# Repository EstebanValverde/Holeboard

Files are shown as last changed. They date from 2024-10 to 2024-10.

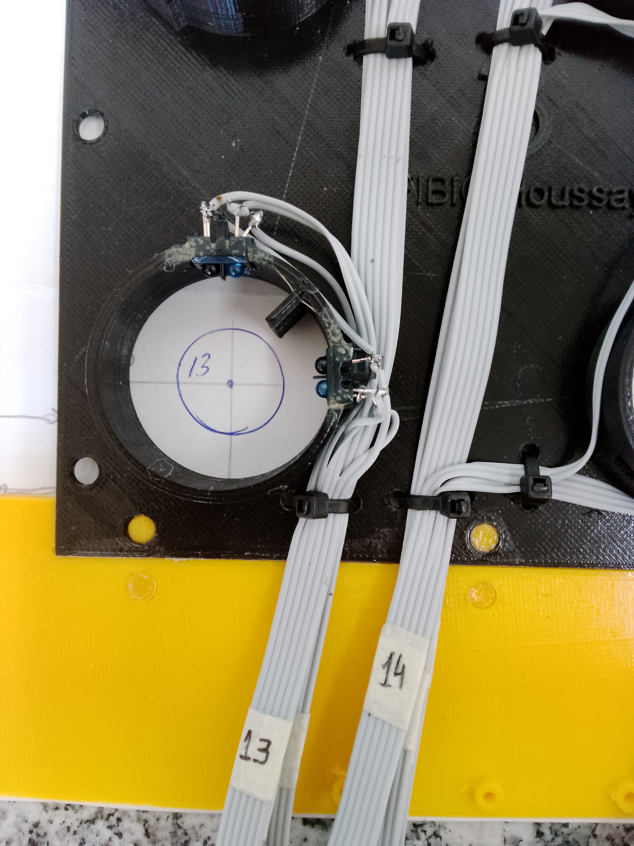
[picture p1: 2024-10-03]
photos/IMG_20231116_135203.jpg

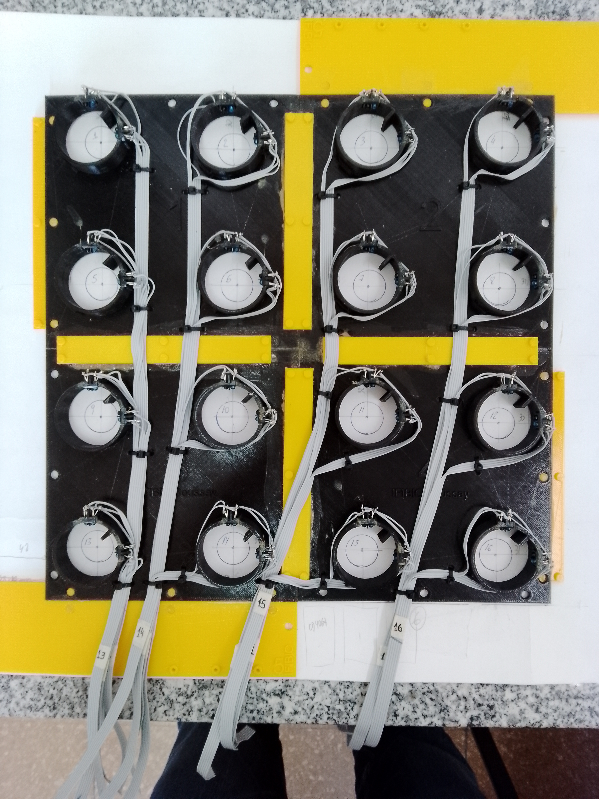
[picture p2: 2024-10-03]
photos/IMG_20231116_135154.jpg

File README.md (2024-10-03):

# Holeboard for mice behavior
The holeboard test (HBT), using a dual-beam infrared system, tracks the behavior (anxiety, stress, neophilia, emotionality) of rodents on a 4x4 grid of holes. Each time the rodent inspects a hole, the device records it, measures the time of the event and its duration, and stores it in a micro SD memory for later analysis. In addition, the device has a TTL-type logic output to synchronize with a video tracking system that records the animal's movement on the grid. As a novelty, this particular HBT has a manual adjustment of the detection threshold and a reading of the grid's basal level. This, on the one hand, allows it to be independent of ambient light conditions, and on the other, to adjust the sensitivity in the detection of an inspection.



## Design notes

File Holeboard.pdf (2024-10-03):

CPA Responsable
Dr. Esteban Valverde

ORDEN DE PROVISIÓN DE SERVICIOS - CPA Nº de ticket

Desarrollo y diagnóstico tecnológico para las
diferentes líneas de investigación
Fecha de Inicio: 10/06/2023 | Fecha de Finalización: 01/02/2024

## Desarrollo de la orden de servicio

### Descripción general

Este Holeboard en particular es un dispositivo de 16 agujeros (Holes), distribuidos en cuatro filas y cuatro columnas, tal y como se observa en la Fig. 1.

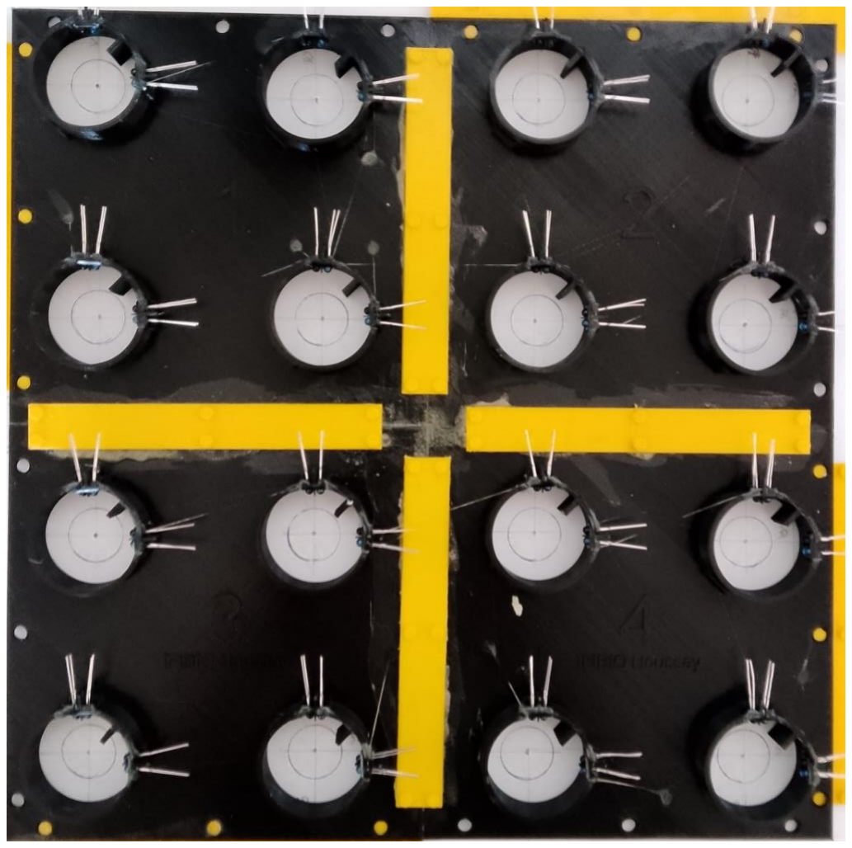
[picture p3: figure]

Figura 1: Vista superior del Holeboard

A su vez, cada “Hole” cuenta con dos sensores infrarrojos TCRT5000 (ver Fig. 2), de manera de detectar cuando el roedor mete la cabeza dentro del agujero. El uso de dos sensores en cada agujero se debe a que pruebas experimentales mostraron que un solo sensor no alcanza para cubrirlo por completo, quedando zonas del Hole que el sensor no detecta.

Como se observa en la Fig. 2, cada Hole tiene un diámetro de 2cm, mientras que el espacio interior debajo del Hole tiene un diámetro de 36cm y una profundidad de 1.5cm, de manera que los sensores quedan dentro de ese espacio. A su vez, los sensores están separados por una pared divisoria para evitar que el emisor de un sensor impacte en el receptor del otro sensor y perjudique la medición.

Se debe notar que el espacio interior de cada Hole es negro, ya que pruebas preliminares mostraron que este color es la mejor condición para el registro, esto es, la NO detección de IR cuando no hay ningún objeto dentro del hole, o mejor dicho, la sensibilidad de detectar cuando el ratón mete la nariz en el hole.

diferentes líneas de investigación

Fecha de Inicio: 10/06/2023 | Fecha de Finalización: 01/02/2024

Además, fue necesario pintar de negro el lado de interno de la tapa del holeboard, por esta misma razón, mientras que el lado superior (externo) quedó blanco para poder seguir mejor con la cámara el movimiento del roedor. Para lograr tener blanco de una lado y negro del otro, primeramente se pintó de blanco mate, con 4 capas, el lado inferior de la tapa del holeboard y sobre esta se dieron dos capas de negro mate, de manera de cubrir toda la superficie. Así, el lado superior, de acrílico blanco semitransparente, se observa blanco y sin pintar, cosa que permite que los roedores deambulen sin el peligro de que empiecen a roer la pintura, y el lado inferior queda completamente negro, cosa que favorece el no reborte del IR dentro de cada hole cuando no hay objetos dentro del hole.

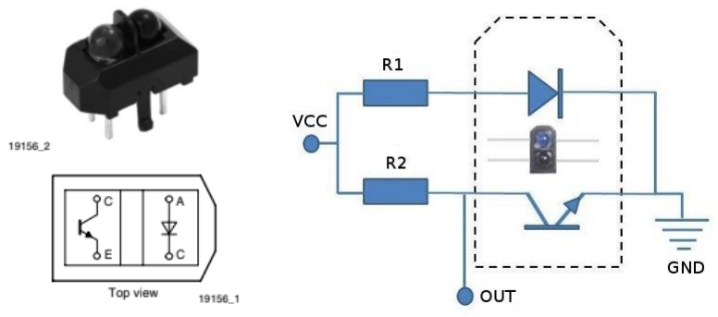
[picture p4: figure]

Figura 2. Detalle de cada “hole”

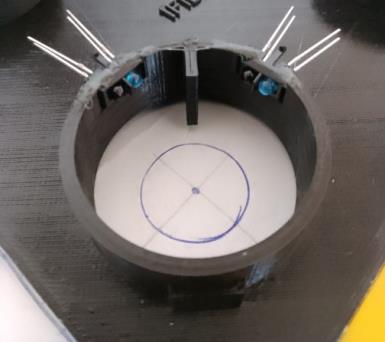
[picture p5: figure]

Un ejemplo de Hole board se puede observar en la Fig. 3. En A se observa el roedor metiendo la cabeza en un Hole, y en B se aprecia cómo esto produce la detección por medio del sensor infrarrojos.

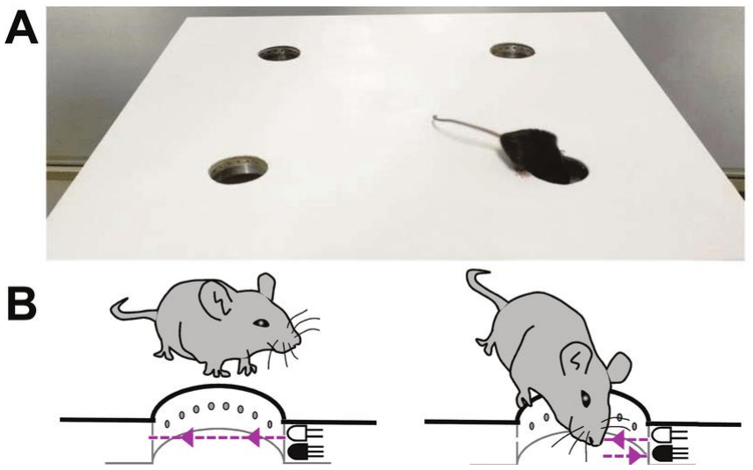
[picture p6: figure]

Figura 3. Ejemplo de un Holeboard. A) Ratón investigando un agujero, B) detección mediante el sensor infrarrojos.

diferentes líneas de investigación

Fecha de Inicio: 10/06/2023 | Fecha de Finalización: 01/02/2024

La placa del Hole board se desarrolló en Freecad (software de desarrollo en 3D) y luego se exportó el diseño para ser impreso en 3D, utilizando material PLA de 1.75mm negro. La impresora 3D es marca Kuttercraft PK3++.

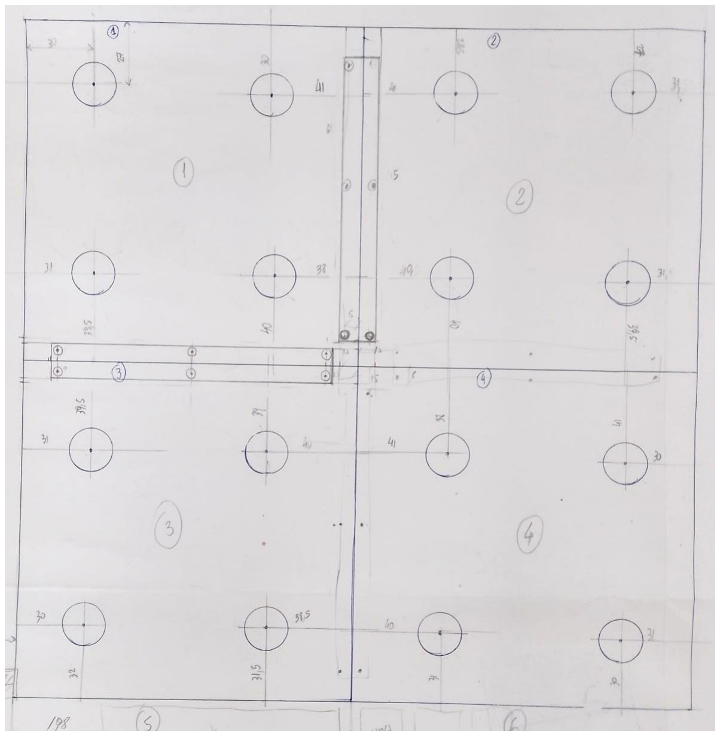
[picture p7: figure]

Figura 4. Diagrama dimensional del Hole board

En la Fig. 4 se observa el diagrama del Hole board con las medidas (tomadas en base a una placa de acrílico blanca, previamente perforada que ya está siendo utilizada en el IFIBIO). Cabe notar que los agujeros de la placa de acrílico no fueron están perfectamente alineadas.

Debido a las dimensiones del Holeboard, que superan ampliamente la capacidad de la impresora, se dividió el desarrollo en 4 bloques de 4 agujeros cada uno, y cada bloque se unió al resto mediante un soporte con encastres, de manera que una vez unido todo (con pegamento) quedara una sola pieza firme y resistente (ver uniones amarillas en la Fig. 1).

Como los agujeros del holeboard no están perfectamente alineados, fue necesario desarrollar cada bloque en Freecad por separado, de manera de hacer coincidir los agujeros con la placa.

diferentes líneas de investigación

Fecha de Inicio: 10/06/2023 | Fecha de Finalización: 01/02/2024

El protocolo es el siguiente: Se “leen” los dos sensores de cada Hole de manera secuencial a una cierta frecuencia (la máxima que permite el software, y menor a 10mseg), de izquierda a derecha y de arriba a abajo, llamados Hole 1 al 16. Cuando se detecta que alguno de ellos está obstruido (posible ratón que metió la cabeza), entonces el sistema se detiene en ese agujero en particular y se queda observando las salidas de ambos fototransistores (FTR). Le idea es detectar con precisión (luego se verá como) las siguientes situaciones:

- Cuando el ratón mete la cabeza
- Cuando el ratón saca la cabeza
- El tiempo que estuvo con la cabeza dentro del hole.

La idea es, en caso de detección, poder medir con precisión momento en el que se mete la cabeza, en el que se la saca y la duración de episodio. Esto se deberá almacenar en una memoria SD de manera de analizar posteriormente el comportamiento del roedor en el Holeboard.

### Circuito eléctrico

En la Fig. 5 se observa el diagrama esquemático de cada Hole. Cada sensor es independiente del otro, pero se activan y leen en simultáneo. Los diodos emisores infrarrojos (IR) emiten cuando el transistor T2 recibe un nivel lógico alto en la base (+5V) a través de la conexión INx. En este momento, el colector de T2 queda a nivel lógico bajo (GND) y permite la circulación de corriente por ambos diodos. El valor de R1 y R3 de 220E asegura una corriente mayor a 20mA necesaria para que el diodo emita. Si INx queda flotando, entonces R4 asegura que la base de T2 quede con un nivel lógico bajo (GND), por lo que el colector de T2 queda en nivel lógico alto y en consecuencia no circula corriente por los diodos emisores.

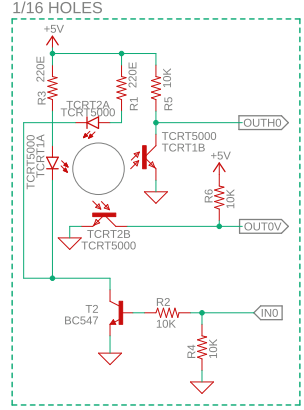
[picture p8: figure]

Figura 5. Diagrama eléctrico de cada Hole diferentes líneas de investigación

Fecha de Inicio: 10/06/2023 | Fecha de Finalización: 01/02/2024

Simultáneamente a la activación de T2, se leen las salidas de los FTRs, OUTxH y OUTxV, que corresponden a cada uno de los sensores “Horizontal” y “Vertical”.

Cuando no hay ningún objeto en el Hole, el FTR no recibe ninguna señal IR, equivalente a un nivel lógico bajo en su base, por lo que el colector de ambos FTRs quedan en nivel lógico alto (+5V). La razón de que el espacio interior de cada Hole debe ser más grande y oscuro, respecto del Hole, es precisamente evitar que la luz IR rebote en la pared del interior del Hole y sea detectada por los FTRs. En consecuencia, si no hay objeto dentro del agujero, nada de la emisión del IR emitido debe ser detectado por los FTRs y su tensión de salida deberá ser cercana a +5V.

Por el contrario, cuando se mete un objeto dentro del Hole (cabeza del ratón), la luz IR rebota en el roedor y es detectada por cada FTR. Con el colector de FTR conectado entre la salida y VCC (+5V) y el emisor a GND, entonces la salida del mismo será un valor analógico entre GND, que es cuando hay obstrucción total del IR (todo el IR rebota en el obstáculo y regresa al FTR), y VCC, que es cuando no hay ningún obstáculo (todo el IR se pierde en la distancia del interior del Hole y nada regresa al FTR).

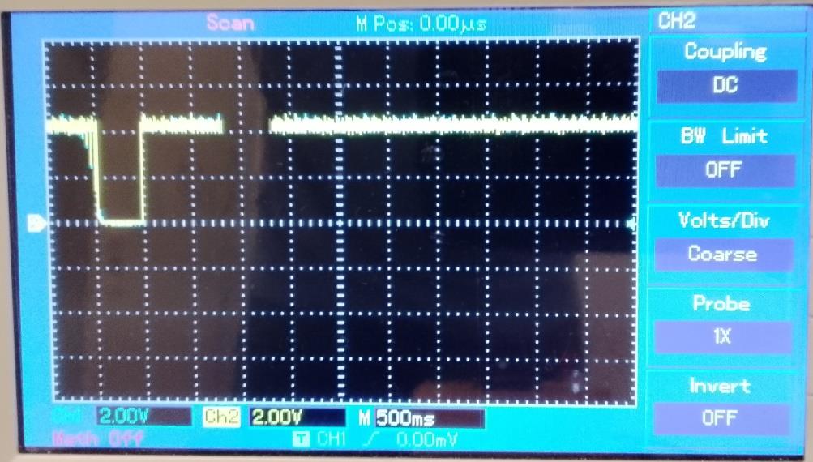
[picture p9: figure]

Figura 6. Salida del osciloscopio de ambos sensores cuando el roedor mete la cabeza

El circuito se completa con tres multiplexores de 16 entradas. Dos de ellos como salidas de cada uno de los 16 pares de FTRs, y el otro como de-multiplexor de entrada de +5V para activar secuencialmente cada Hole.

En la Fig. 6 se observa la salida del oscilocopio de ambos sensores (vertical y horizontal), casi superpuestas, de todos los 16 holes. Se observa que cuando no hay nada dentro de algún hole las tensiones de salida son aproximadamente 4Volts (lo ideal sería +5V pero hay un rebote mínimo dentro de cada hole del IR que hace descender ese valor, sumado al valor de polarización del fototransistor).

La misma figura muestra el barrido de los 16 holes a una frecuencia muy rápida (el tiempo en que tarda en ciclar el lazo principal del programa de control, y que es menor a los 10mseg). En el momento en que se detecta que hay un objeto en un hole, el programa se detiene en dicho hole y se queda esperando a que ese objeto se retire de ese mismo hole. En la figura se diferentes líneas de investigación

Fecha de Inicio: 10/06/2023 | Fecha de Finalización: 01/02/2024

observa como la caida a 0V de ambos sensores en algún hole específico. El programa principal almacenará el número de hole, el momento en que el objeto se introdujo en el hole y la duración del evento.

Se utilizarán los multiplexores analógicos 74HC4067. Cuando se los utiliza como multiplexor, la salida tiene el valor de la entrada seleccionada; funcionan como simples resistencias bidireccionales de paso para valores analógicos entre 0 y +5V, y se leerán secuencialmente los valores de OUTxH y OUTxV.

Cuando se lo usa como de-multiplexor, esto es, una entrada a 16 salidas, las salidas INx que no son seleccionadas están en estado es de alta impedancia, mientras que la seleccionada tiene un valor de salida igual al del pin de entrada, que es +5V. Por esta razón, se utilizan los resistores de derivación a tierra en la base de los transistores, de manera de asegurar que un Hole en particular esté emitiendo IR mientras que los demás están permanecen apagados.

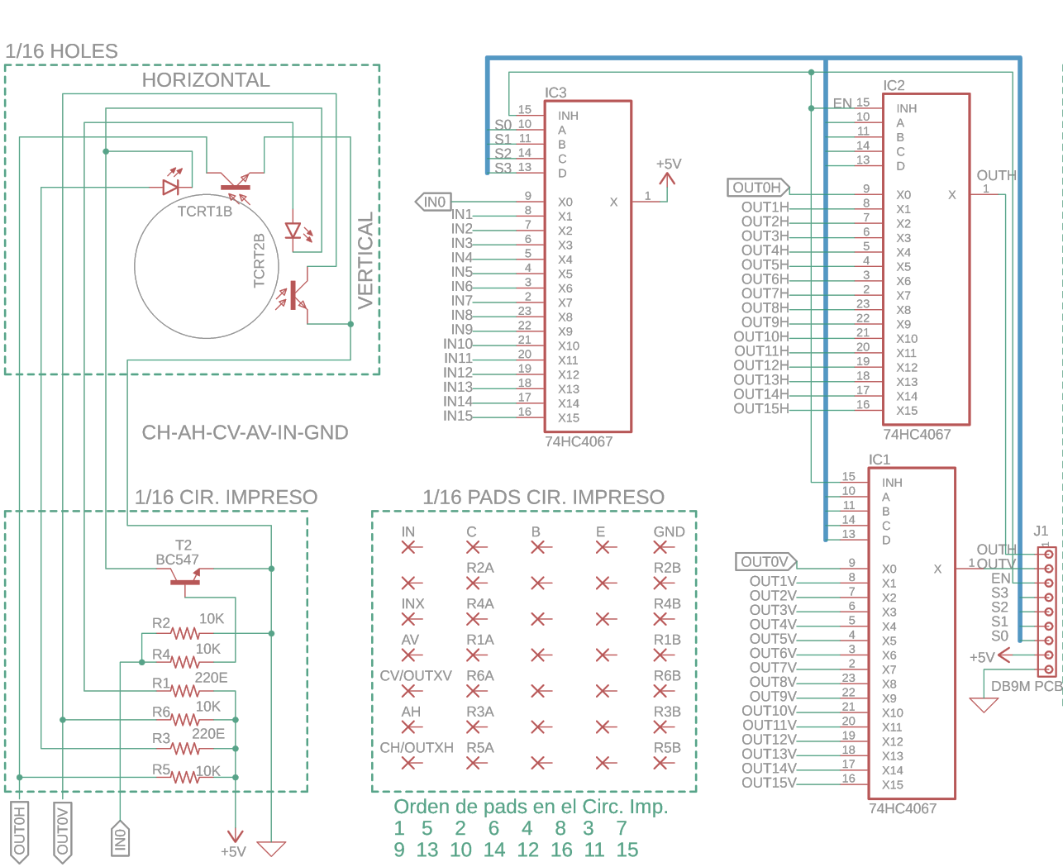
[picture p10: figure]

Figura 7. Conexionado de los multiplexores de la placa Hole board

La razón de desarrollar de esta manera el circuito es por el consumo. Si cada diodo IR consume 20mA, significa que cada Hole consume 40mA para emitir IR. Si se permite que todos los Holes emitan al mismo tiempo (aunque no se estén escaneando sus salidas), el consumo total del Hole board es de 640mA, necesitándose fuente adicional para esto. Al utilizar un de-multiplexor como el propuesto, sólo el Hole en cuestión está consumiendo 40mA mientras que el resto del sistema no consume corriente.

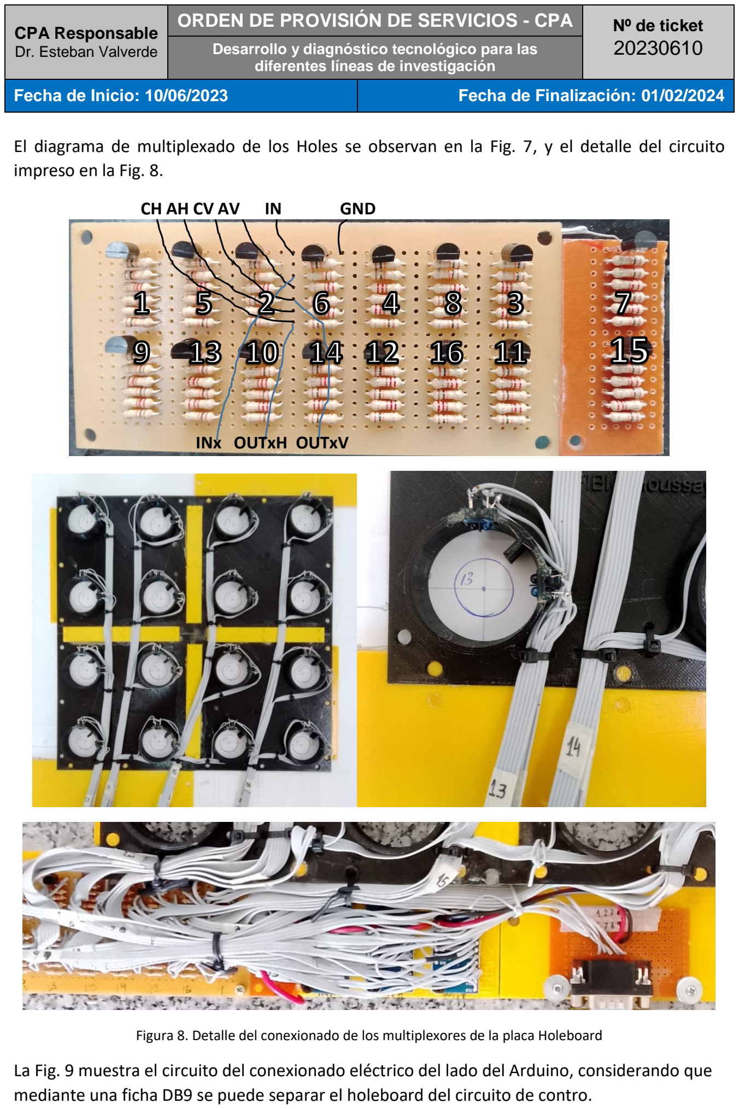
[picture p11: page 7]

diferentes líneas de investigación

Fecha de Inicio: 10/06/2023 | Fecha de Finalización: 01/02/2024

El diagrama de multiplexado de los Holes se observan en la Fig. 7, y el detalle del circuito impreso en la Fig. 8.

Figura 8. Detalle del conexionado de los multiplexores de la placa Holeboard

La Fig. 9 muestra el circuito del conexionado eléctrico del lado del Arduino, considerando que mediante una ficha DB9 se puede separar el holeboard del circuito de contro.

CH AH CV AV | IN | GND

INx OUTxH OUTxV

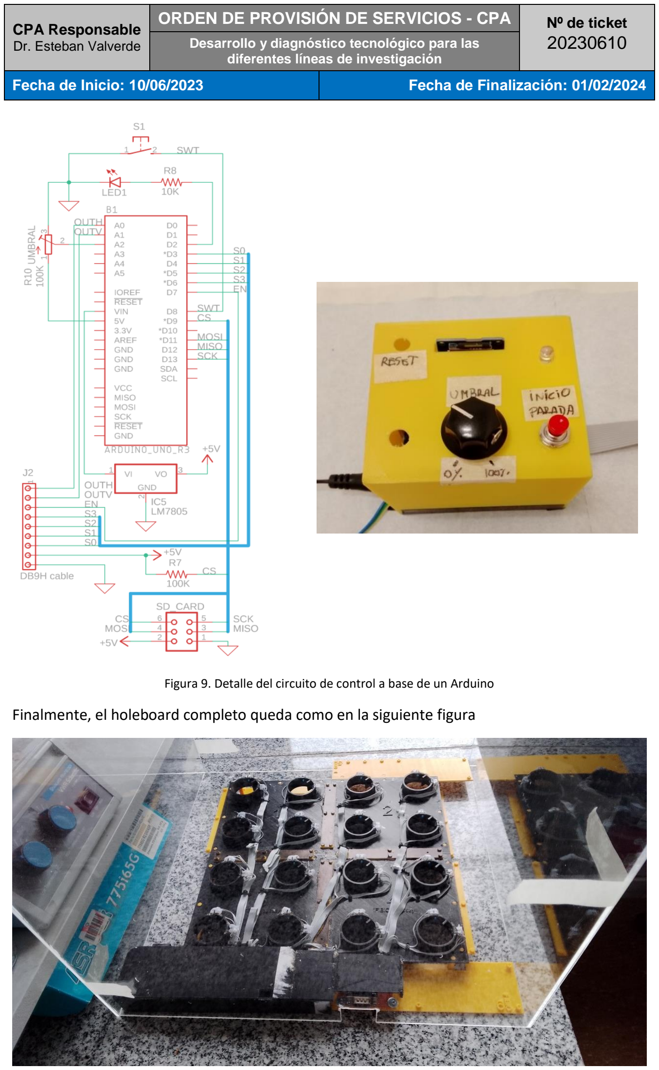
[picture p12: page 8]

diferentes líneas de investigación

Fecha de Inicio: 10/06/2023 | Fecha de Finalización: 01/02/2024

Figura 9. Detalle del circuito de control a base de un Arduino

Finalmente, el holeboard completo queda como en la siguiente figura

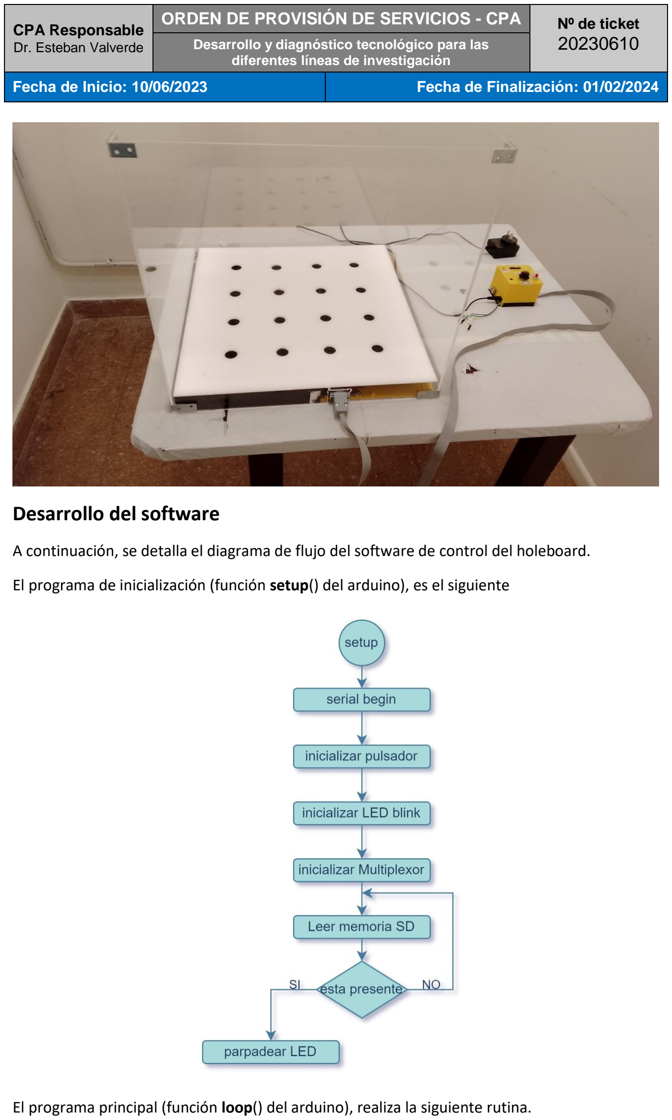
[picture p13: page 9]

diferentes líneas de investigación

Fecha de Inicio: 10/06/2023 | Fecha de Finalización: 01/02/2024

### Desarrollo del software

A continuación, se detalla el diagrama de flujo del software de control del holeboard.

El programa de inicialización (función setup() del arduino), es el siguiente

El programa principal (función loop() del arduino), realiza la siguiente rutina.

diferentes líneas de investigación

Fecha de Inicio: 10/06/2023 | Fecha de Finalización: 01/02/2024

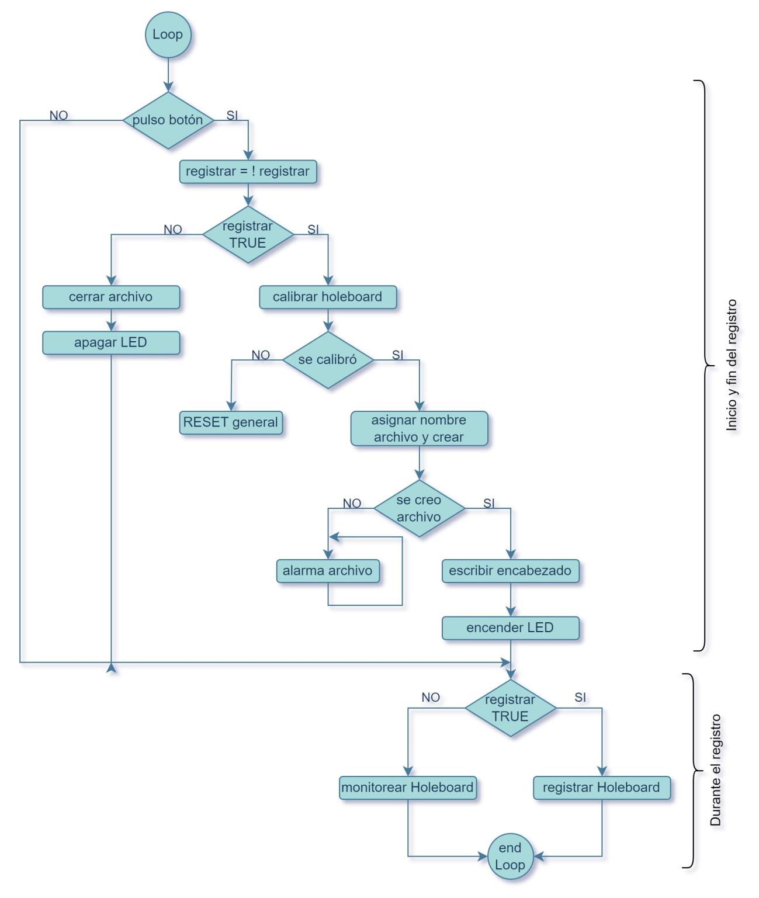
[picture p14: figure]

A continuación, se muestran los diagramas de flujo de las funciones principales del programa: “calibración holeboard” (función bool calibrarHoleboard(void)) y “registrar holeboard” (función void registrarHoleboard(void)).

A su vez, la función calibrarHoleboard llama internamente a la función uint8_t lecturaMaximosHole(uint8_t i, int umbral).

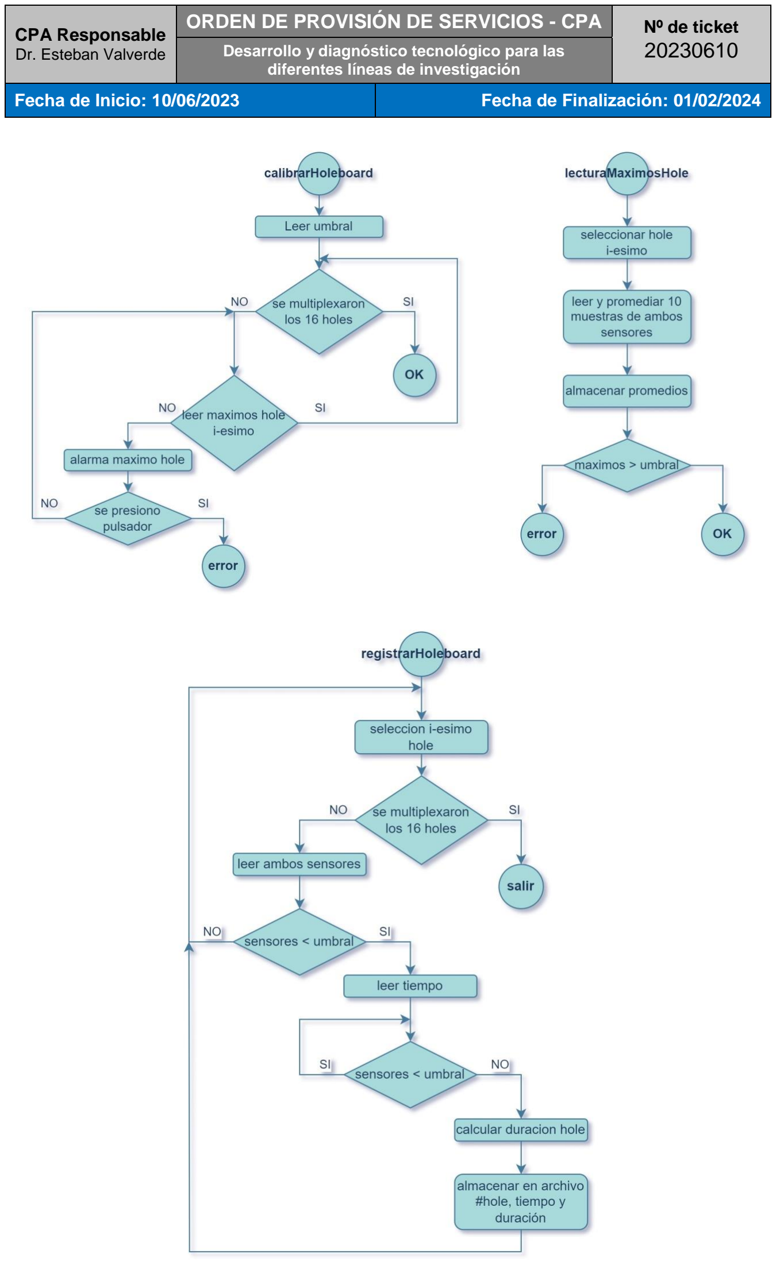
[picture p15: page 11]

diferentes líneas de investigación

Fecha de Inicio: 10/06/2023 | Fecha de Finalización: 01/02/2024

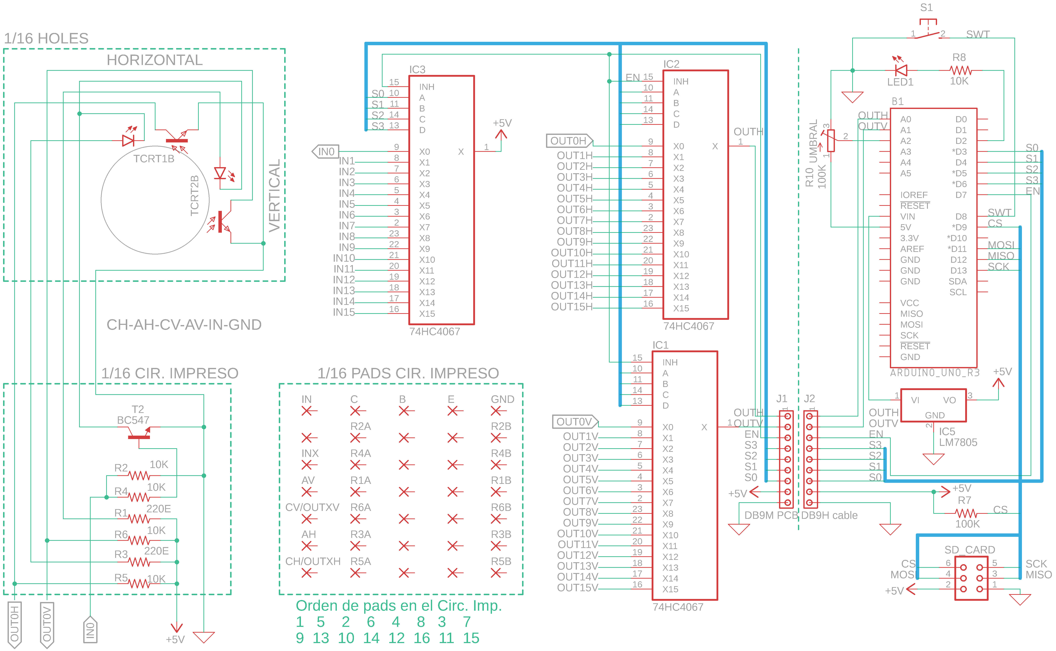
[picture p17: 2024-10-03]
photos/holeboard diagramacion.png

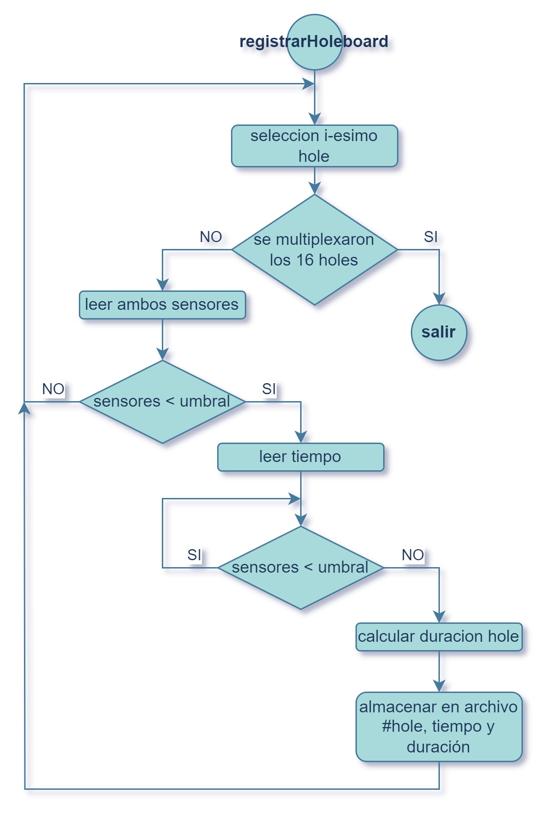
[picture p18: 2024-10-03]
photos/Holeboard - registro.jpg

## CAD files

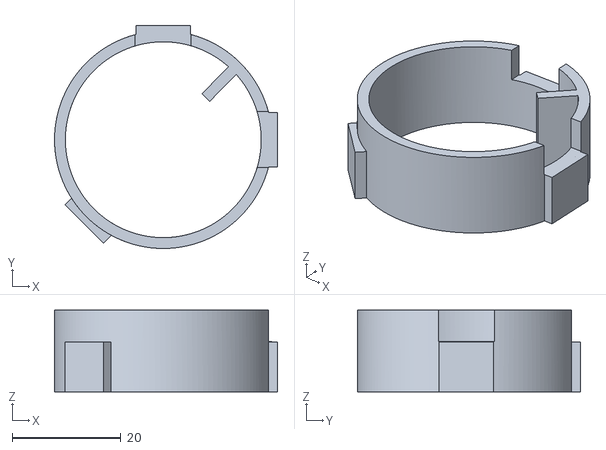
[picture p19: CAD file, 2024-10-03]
modelo 3D/Soporte TCRT5000.stl
41.0 x 41.0 x 15.0

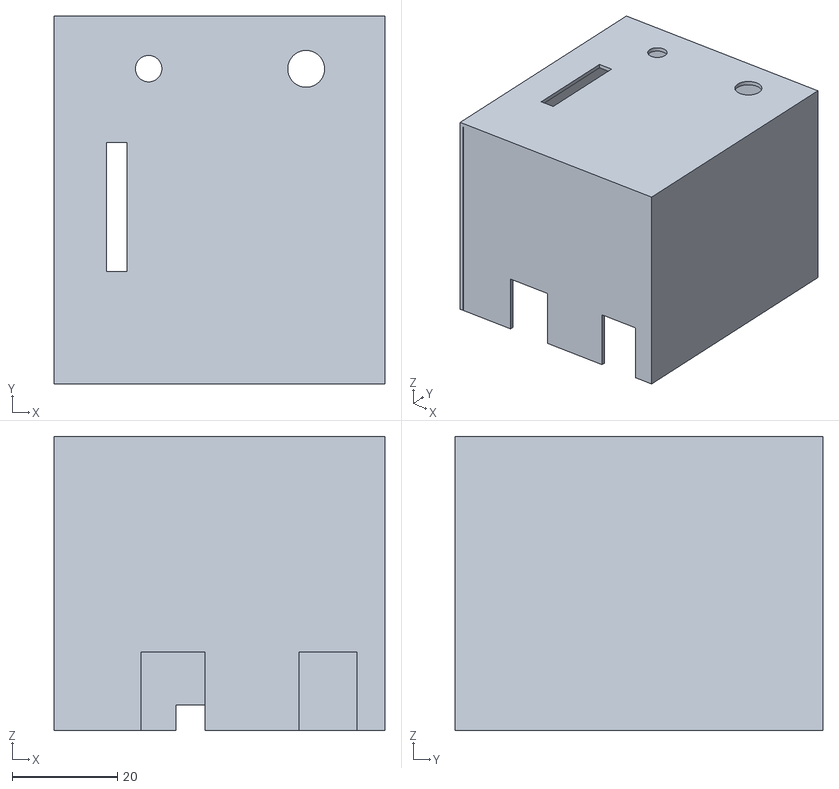
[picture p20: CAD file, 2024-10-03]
modelo 3D/Tapa Gabinete Arduino.stl
63.0 x 70.0 x 56.0

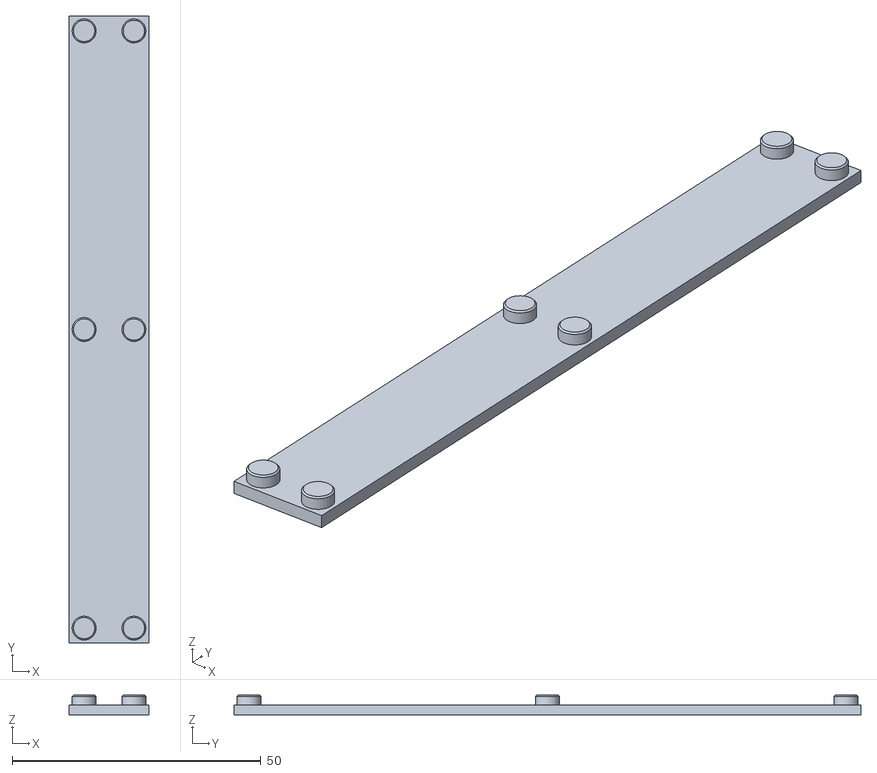
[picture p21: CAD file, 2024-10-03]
modelo 3D/holeboard Union.stl
16.0 x 126.0 x 4.00

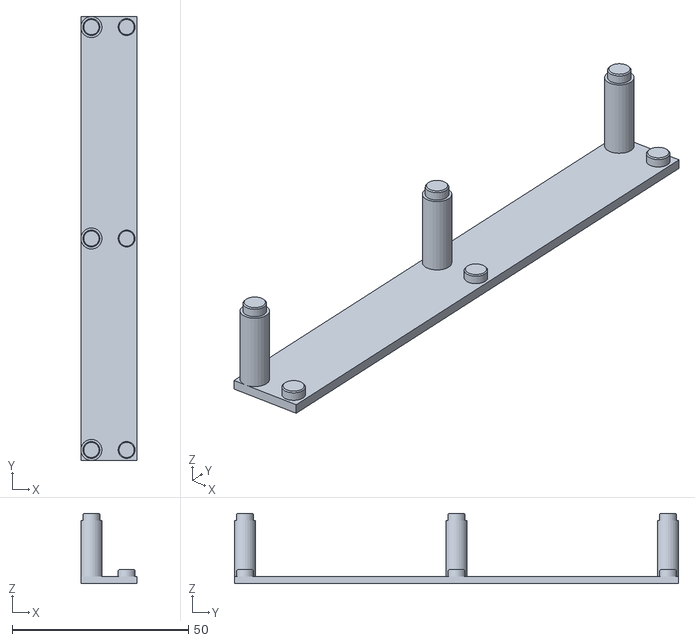
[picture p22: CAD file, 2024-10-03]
modelo 3D/holeboard Union 2.stl
16.0 x 126.0 x 20.0

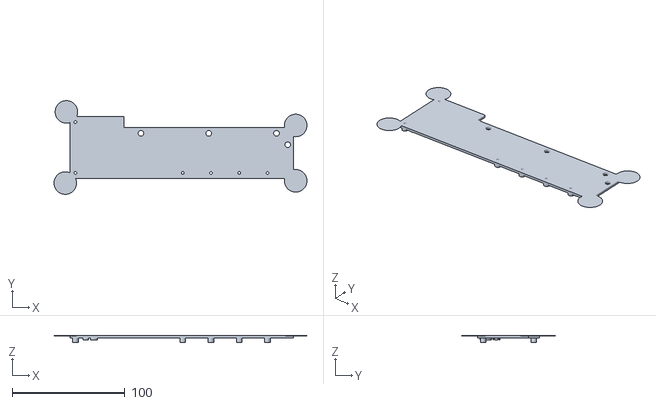
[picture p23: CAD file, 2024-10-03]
modelo 3D/holeboard completo 6.stl
224.0 x 83.0 x 6.00

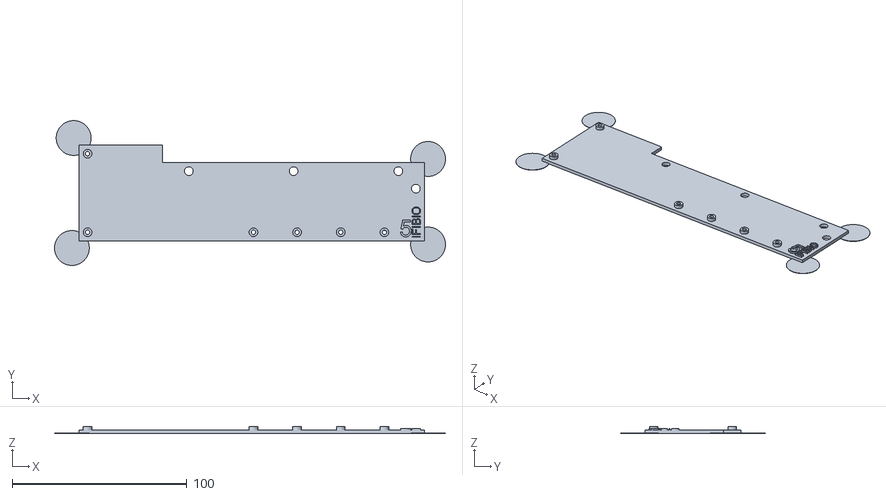
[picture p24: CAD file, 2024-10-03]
modelo 3D/holeboard completo 5.stl
224.0 x 83.0 x 4.00

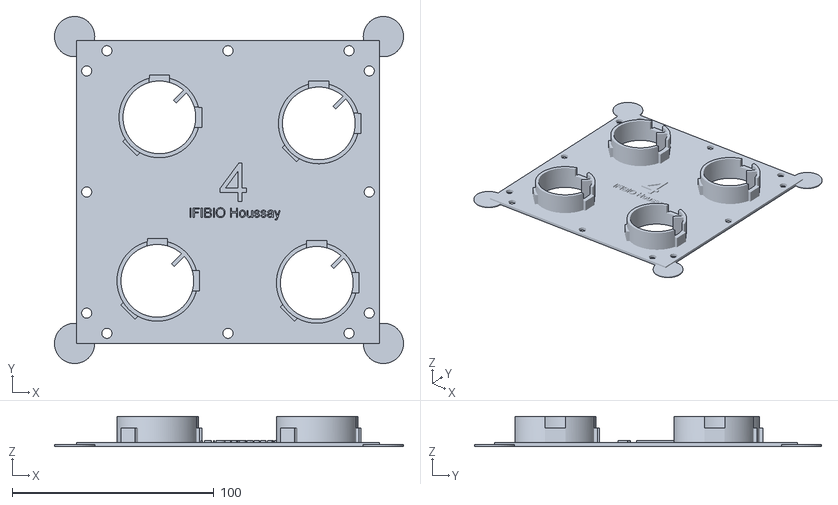
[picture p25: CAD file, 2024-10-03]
modelo 3D/holeboard completo 4.stl
173.0 x 171.9 x 15.0

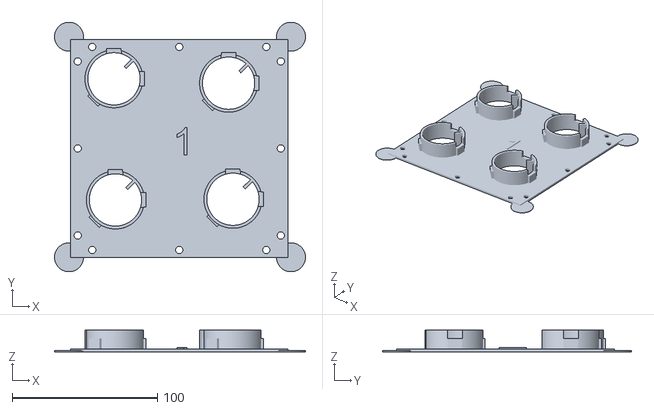
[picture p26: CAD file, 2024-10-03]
modelo 3D/holeboard completo 1.stl
173.0 x 171.9 x 15.0

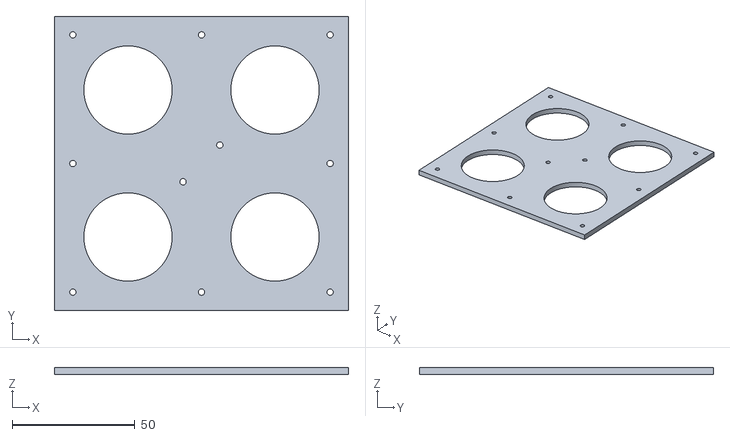
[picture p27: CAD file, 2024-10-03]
modelo 3D/holeboard-Body.stl
120.0 x 120.0 x 3.00

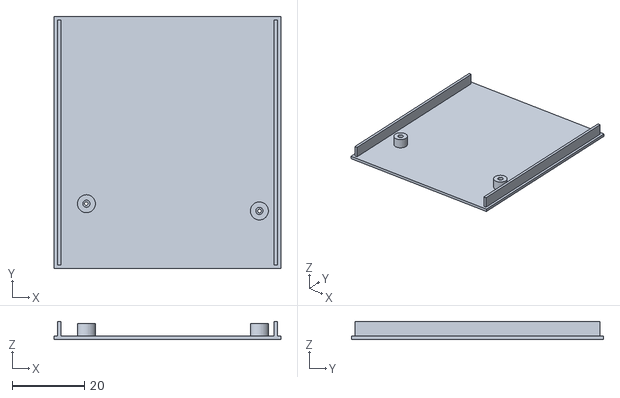
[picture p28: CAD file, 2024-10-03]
modelo 3D/Base Gabinete Arduino.stl
63.0 x 70.0 x 5.00

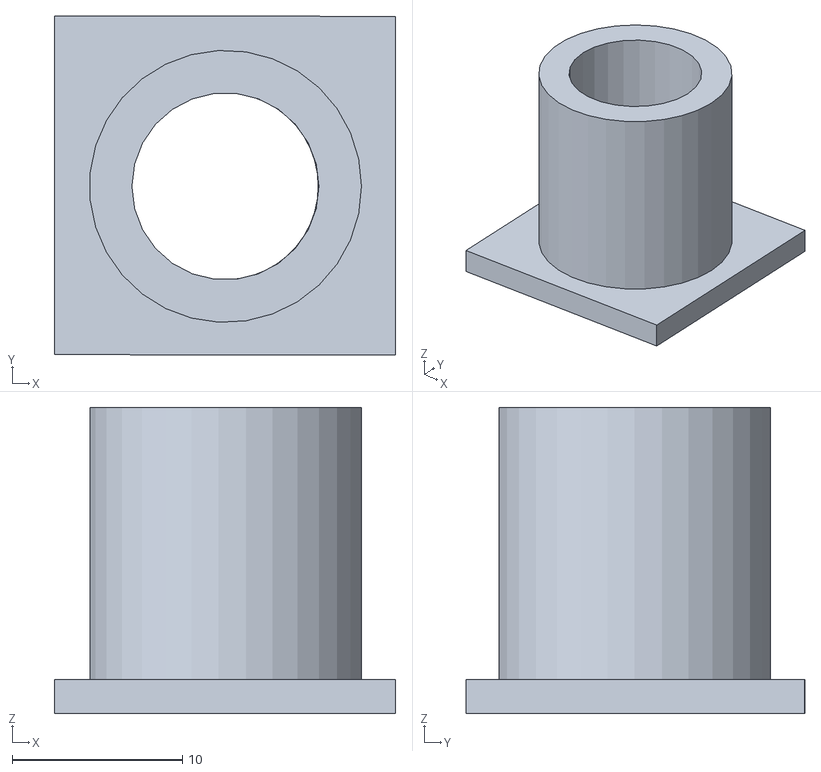
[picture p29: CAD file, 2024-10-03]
modelo 3D/holeboard Union 3.stl
20.1 x 19.9 x 18.0

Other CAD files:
modelo 3D/holeboard completo 3.stl
modelo 3D/holeboard completo 2.stl

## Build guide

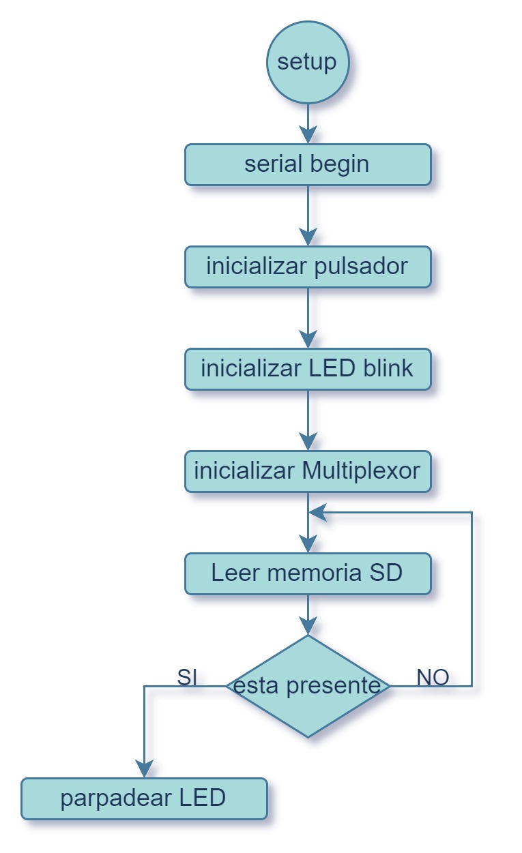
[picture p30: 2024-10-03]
photos/Holeboard - setup.jpg

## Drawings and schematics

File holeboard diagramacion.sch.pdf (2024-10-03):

## 1/16 HOLES HORIZONTAL

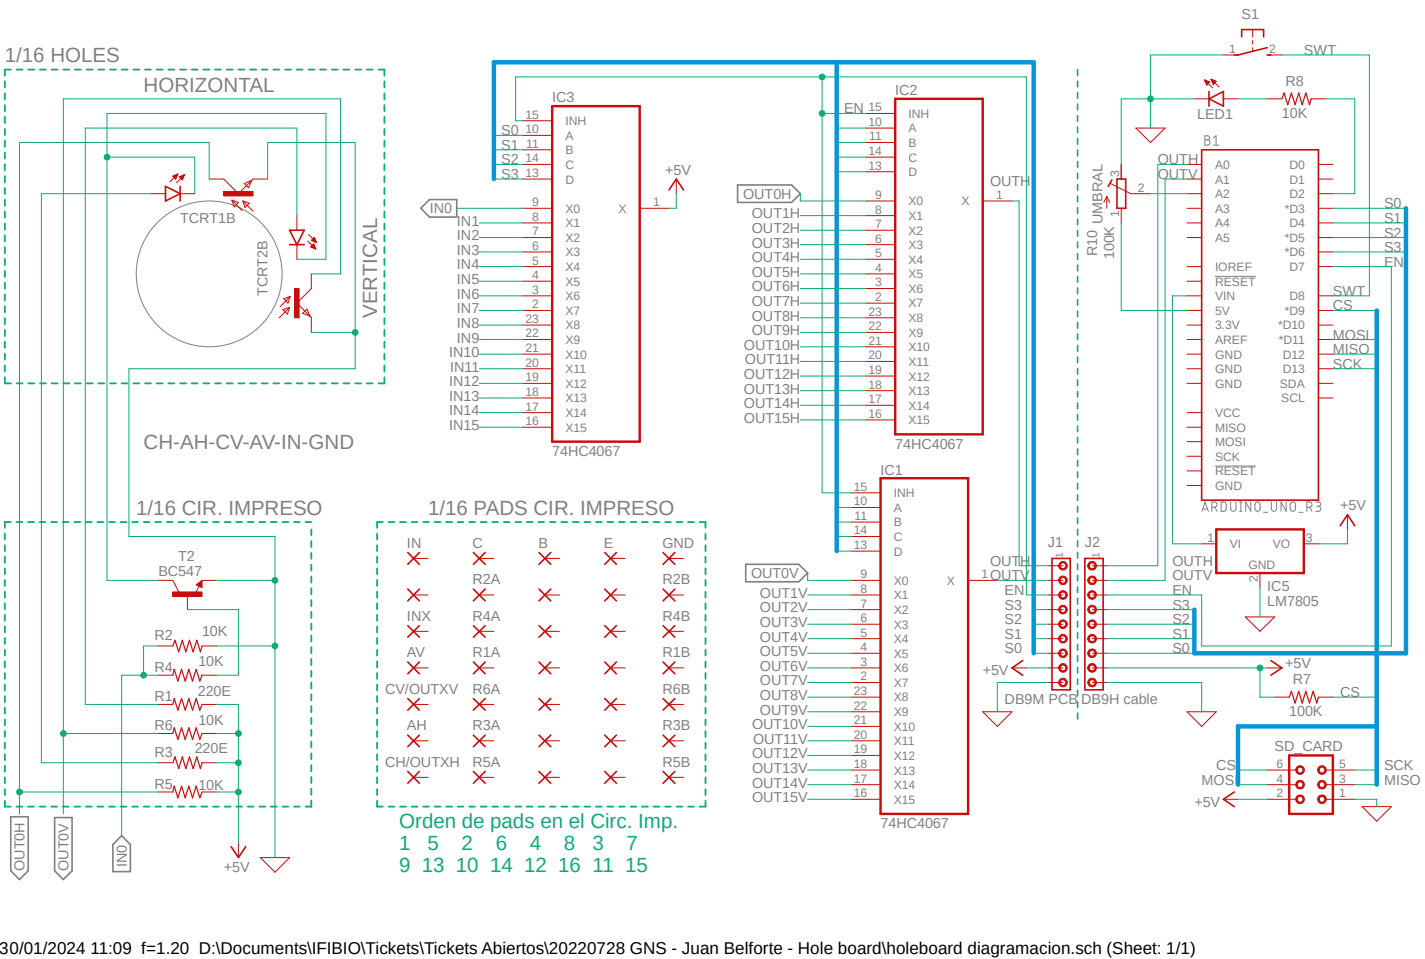
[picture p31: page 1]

S2
S3

X8 23
X9 22
X10 21
X11 20
X12 19
X13 18
X14 17
X15 16

CH-AH-CV-AV-IN-GND

Orden de pads en el Circ. Imp.

30/01/2024 11:09 f=1.20 D:\Documents\IFIBIO\Tickets\Tickets Abiertos\20220728 GNS - Juan Belforte - Hole board\holeboard diagramacion.sch (Sheet: 1/1)

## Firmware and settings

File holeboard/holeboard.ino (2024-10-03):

#include <CD74HC4067.h>
#include <SdFat.h>
//#include <EEPROM.h>
#include <Blink.h>
#include <Flag.h>

// -----------------------------------------------------------------
// pines y clase del holeboard
#define PINEN   B10000000 // EN Pin 7
#define PINS3S0 B01111000 // S3-S0 Pines 6-3 
#define DISPLACE 3 // bits que se desplaza el canal para encajar en PINS3S0
#define PINH A0 // entrada horizontal de cada hole
#define PINV A1 // entrada vertical de cada hole
#define PINUMBRAL A2 // entrada del nivel de umbral
CD74HC4067 mux; // clase multiplexor

int percentUmbral; // porcentaje de amplitud para considerar que se activo un hole
//int outV, outH; // almacena los valores de sensor horizontal y vertical
int outVmax[CHANNEL_SIZE]; // valores maximos de sensores verticales para la calibracion
int outHmax[CHANNEL_SIZE]; // valores maximos de sensores horizontales para la calibracion

// -----------------------------------------------------------------
// pin y clase de la memoria SD
const int SD_CS = 9; // pin CS del modulo de memoria SD
uint8_t fIndex = 0; // es el valor numerico del nombre del archivo: 0 - 255
#define FSIZE 13
char fName[FSIZE+1]; // nombre del archivo en formato 8.3: 00000012.csv
char fRow[100]; // almaceno cada renglon del archivo con los datos registrados
SdFat SD; // clase SD para manejar la memoria SD
SdFile file; // clase file para manejar archivos

//-------------------------------------------------------------------
// pulsador y led de aviso
#define PINLED 2 // pin donde esta conectado el LED
Blink blink; // clase blink que maneja el parpadeo del led
#define PINSWT 8 // pin donde esta conectado el pulsador a masa
Flag swt; // con la clase Flag pregunto si se esta prsionando el pulsador

//-------------------------------------------------------------------
// variables generales
// registrar = true indica que se esta en proceso de registro, esto es
// crear arachivo, leer holeboard, blink led, etc. Si es false, se cierra
// el archivo y no se hace nada mas hasta que vuelva a estar en true
bool registrar = false;
uint32_t inicio, start, length, time; // manejo de tiempos 

//-------------------------------------------------------------------
void setup()
{
  // inicializo puerto serie. Siempre voy a enviar datos aunque no haya
  // una terminal conectada para leerlos
  delay(1000);
  Serial.begin(9600);

  // inicializo el boton de switch, con pullup interno, porque esta conectado
  // entre el pin PINSWT y masa. Le doy un delay de 100mseg para debaucing
  swt.begin(PINSWT, INPUT_PULLUP);
  swt.setFlagDelay(100);

  // inicializo la clase blink para el parpadeo del led. esta funcion asigna
  // el pin fisico donde esta soldado el led, y lo deja apagado
  blink.init(PINLED, 0);

  // siempre debe ir esta funcion despues de inicializar el puerto serie
  mux.init(PINS3S0, DISPLACE, PINEN, PINH, PINV);
 
  // verifico que este puesta la memoria SD
  if(!SD.begin(SD_CS))
  {
    // sino esta presente o hay error, aviso por puerto serie
    // y detengo el programa
    Serial.println(F("Inserte Memoria SD"));
    blink.setRate(1000);
    blink.start();
    while(!SD.begin(SD_CS)) blink.blink();
    blink.stop();
    asm volatile ("jmp 0"); // por las dudas, reinicio el sistema
  }
  Serial.println(F("Memoria SD presente"));
  
  // espero un segundo para que todo se estabilice, envio
  // un parpadeo rapido para saber que se inicio el programa
  blink.setRate(100);
  blink.start();
  inicio = millis();
  while(millis()-inicio < 1000) blink.blink();
  blink.stop();
  Serial.println(F("Dispositivo listo"));
}

//-------------------------------------------------------------------
void loop()
{
  // primero que nada leo el switch, si se pulso, puede significar que
  // se comienza un registro o que se termina. Entonces pregunto si
  // hubo cambio en el estaado del pulsador
  if(swt.isChanged() == true)
  {
    // si hubo cambio de estado, solo me interesa el estado LOW (que es
    // cuando se presiona el boton. HIGH es cuando se suelta y no interesa)
    if(swt.getState() == LOW)
    {
      // simplemente invierto el estado de "registrar" para pasar de modo
      // registrar a modo no registrar
      registrar = !registrar;
      // si ahora paso a modo registrar, inicio el blink del led para indicar
      // que se esta registrando. Si paso a modo no registrar, dejo de hacer
      // parpadear el led. Aqui tambien asgino y abro archivo de datos a registrar
      if(registrar == true)
      {
        // calibracion del holeboard. Se hace cada vez que se empieza un nuevo registro
        Serial.println(F("calibrando..."));
        
        // si no pude calibrar, reinicio el sistema
        if(!calibrarHoleboard())
        {
          asm volatile ("jmp 0");
        }

        // asingo nombre de archivo
        getNextFileName(fName);
        //fIndex = EEPROM.read(0);
        //sprintf(fName, "%08u.csv", fIndex);
        Serial.print(F("asignando archivo "));
        Serial.println(fName);

        // actualizo la eeprom para el proximo nombre de archivo
        //fIndex = fIndex + 1;
        //EEPROM.update(0, fIndex);

        // abro el archivo para almacenar datos
        if(!file.open(fName, O_RDWR | O_CREAT))
        {
          // si no puedo crear/abrir el archivo, aviso por puerto
          // serie y detengo el programa
          Serial.print(F("Error File "));
          Serial.println(fName);
          blink.setRate(500);
          blink.start();
          while(!file.open(fName, O_RDWR | O_CREAT)) blink.blink();
          blink.stop();
        }
        Serial.print(fName);
        Serial.println(F(" creado correctamente"));
        file.println(F("# hole;tiempo al inicio;duracion de cada evento"));
        sprintf(fRow, "umbral %d %%", percentUmbral);
        file.println(fRow);

        // si llegue aca es porque esta presente la memoria SD, 
        // y pude crear y abrir el nuevo archivo de datos
        Serial.println("registrando...");
        inicio = millis();
        blink.start();
      }
      else
      {
        // cierro archivo
        Serial.println("finalizando...");
        Serial.print(F("cerrando archivo "));
        Serial.println(fName);
        file.close();

        // termino el parpadeo del led que indica que ya se cerro
        // el archivo de datos y no se registra mas
        blink.stop();
      }
    }
  }
  // la funcion blink() esta presente siempre y dependiendo de start() y stop()
  // va a hacer que el led parpadee al rate que se configuro al inicio del programa
  blink.blink();

  // aqui miro el estado de registrar para saber si hago el registro o no
  if(registrar == true)
  {
    // estoy registrando
    registrarHoleboard();
  }
  else
  {
    // si no estoy haciendo nada multiplexo los canales para poder ver en el 
    // osciloscopio el nivel de cada hole
    for(uint8_t i=0; i<CHANNEL_SIZE; i++)
    {
      // recorro los 16 agujeros del holeboard
      mux.channel(i);
      delay(10);
    }
  }
}

//-------------------------------------------------------------------
// realiza la calibracion del holeboard. Si alguno de los sensores indica
// menos de 50%. Se concluye que hay error y se detiene el programa
bool calibrarHoleboard(void)
{
  int umbral;

  // leo el valor del umbral que está en el potenciometro
  umbral = analogRead(PINUMBRAL);
  percentUmbral = (float) umbral * 100.0 / 1023.0;
  Serial.print(F("Umbral "));
  Serial.print(percentUmbral);
  Serial.println("%");

  // recorro los holes y leo los valores maximos medidos en cada uno
  // si alguno esta por debajo del umbral, considero que no se puede registrar
  // y se entra en modo de alerta, titilando el led
  for(uint8_t i=0; i<CHANNEL_SIZE; i++)
  {
    // recorro los 16 agujeros del holeboard
    // si alguno de ellos disminuyo su amplitud al 500 cuentas, considero que el
    // esta registrando mal ese hole, por ejemplo, hay mucha luz ambiente
    if(!lecturaMaximosHole(i, umbral))
    {
      Serial.print(F("Error de amplitud en el hole "));
      Serial.println(i+1);
      blink.setRate(250);
      blink.start();
      while(!lecturaMaximosHole(i, umbral))
      {
        blink.blink();
        // puedo o bien ver que pasa y seguir la calibracion, o abortarla
        if(swt.isChanged() == true)
          if(swt.getState() == LOW)
          {
            blink.stop();
            return false;
          }
      }
      blink.stop();
    }
  }
  Serial.println(F("Holeboard calibrado"));
  return true;
}

//-------------------------------------------------------------------
// es el algoritmo que lee los valores de calibracion del hole board
// deberian ser cercanos al maximo valor de lectura del ADC
uint8_t lecturaMaximosHole(uint8_t iesimo, int umbral)
{
  // habilito el  i-esimo canal
  mux.channel(iesimo);

  // leo los valores de ambos sensores IR (horizontal y vertical)
  // del i-esimo hole
  outHmax[iesimo] = 0;
  outVmax[iesimo] = 0;
  for(uint8_t j=0; j<10; j++)
  {
    outHmax[iesimo] = outHmax[iesimo] + mux.readOutH();
    outVmax[iesimo] = outVmax[iesimo] + mux.readOutV();
    delay(10);
  }
  outHmax[iesimo] = outHmax[iesimo] / 10;
  outVmax[iesimo] = outVmax[iesimo] / 10;

  // si esta debajo del umbral, no puedo usar el hole
  if(outHmax[iesimo] < umbral || outVmax[iesimo] < umbral) return false;
  else return true;
}

//-------------------------------------------------------------------
// realiza la medicion del holeboard. Para ello recorre todos los agujeros
// y se fija si alguno disminuyo al 50% de su amplitud maxima para el menos
// uno de los dos sensores de cada agujero. En ese caso se considera que el
// raton metio la cabeza. Entonces se registran los datos en el archivo
void registrarHoleboard(void)
{
  static int outV, outH; // almacena los valores de sensor horizontal y vertical

  for(uint8_t i=0; i<CHANNEL_SIZE; i++)
  {
    // recorro los 16 agujeros del holeboard
    mux.channel(i);
    // leo los valores de ambos sensores IR (horizontal y vertical)
    outH = mux.readOutHpercent(outHmax[i]);
    outV = mux.readOutVpercent(outVmax[i]);
    // si alguno de ellos disminuyo su amplitud al 50%, considero que el
    // animal metio la cabeza adentro
    if(outH < percentUmbral || outV < percentUmbral)
    {
      // obtengo el momento en que metio la cabeza desde que comenzo el registro,
      // o sea, desde que se abrio el archivo para comenzar a registrar
      time = millis()-inicio;

      // ahora, mientras alguno de los sensores este por debajo del 50% me quedo
      // esperando, esto es, voy a medir cuanto tiempo esta el roedor con la cabeza
      // metida dentro del agujero
      blink.stop();
      start = millis();
      while(outH < percentUmbral || outV < percentUmbral)
      {
        outH = mux.readOutHpercent(outHmax[i]);
        outV = mux.readOutVpercent(outVmax[i]);
      }
      length = millis()-start;
      blink.start();

      // considero metidas de cabeza en el hole mayores a 10mseg
      //if(length > 10)
      //{
        // ahora armo el array de salida con la siguiente informacion:
        // nro de hole, tiempo desde el inicio del registro, duracion con la cabeza
        // dentro del agujero, amplitudes horizontal y vertical respectivamente
        sprintf(fRow, "%d;%lu;%lu", i+1, time, length);

        // almaceno la info en el archivo y tambien la envio por puerto serie
        file.println(fRow);
        Serial.println(fRow);
      //}
    }
  }
}

//-----------------------------------------------------------------------
// esta funcion cuenta cuántos archivos csv hay en la memoria SD empezando
// consecutivamente desde el 00000000.csv en adelante. Cuando uno de esos
// no lo encuentra, significa que se llego hasta el archivo anterior. Por ej
// si no existe el archivo 00000017.csv es porque en la memoria SD estan
// desde el 00000000.csv hasta el 00000016.csv. Cada vez que se borra la 
// memoria, se comienza nuevamente desde el 0000000.csv
void getNextFileName(char *fName)
{
  uint16_t c = 0;
  while(1)
  {
    // pregunto en orden creciente por 0000000 a 0000xxxx.csv
    sprintf(fName, "%08u.csv", c);
    // si existe, me fijo el siguiente archivo en orden creciente
    // si no existe, entonces devuevo ese nombre de archivo
    if(SD.exists(fName)) c++; 
    else break;              
  }
}
